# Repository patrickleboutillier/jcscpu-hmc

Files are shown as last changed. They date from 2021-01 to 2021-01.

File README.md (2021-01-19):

# jcscpu-hmc

But How Do It Know?: http://www.buthowdoitknow.com/

# Video Series

This project contains the code that runs in the implementation of John Clark Scott's CPU detailed here: 

https://www.youtube.com/playlist?list=PLYE0XunAbwfDvfabOlNWLViRcMI54M6CR

# Project Schematic
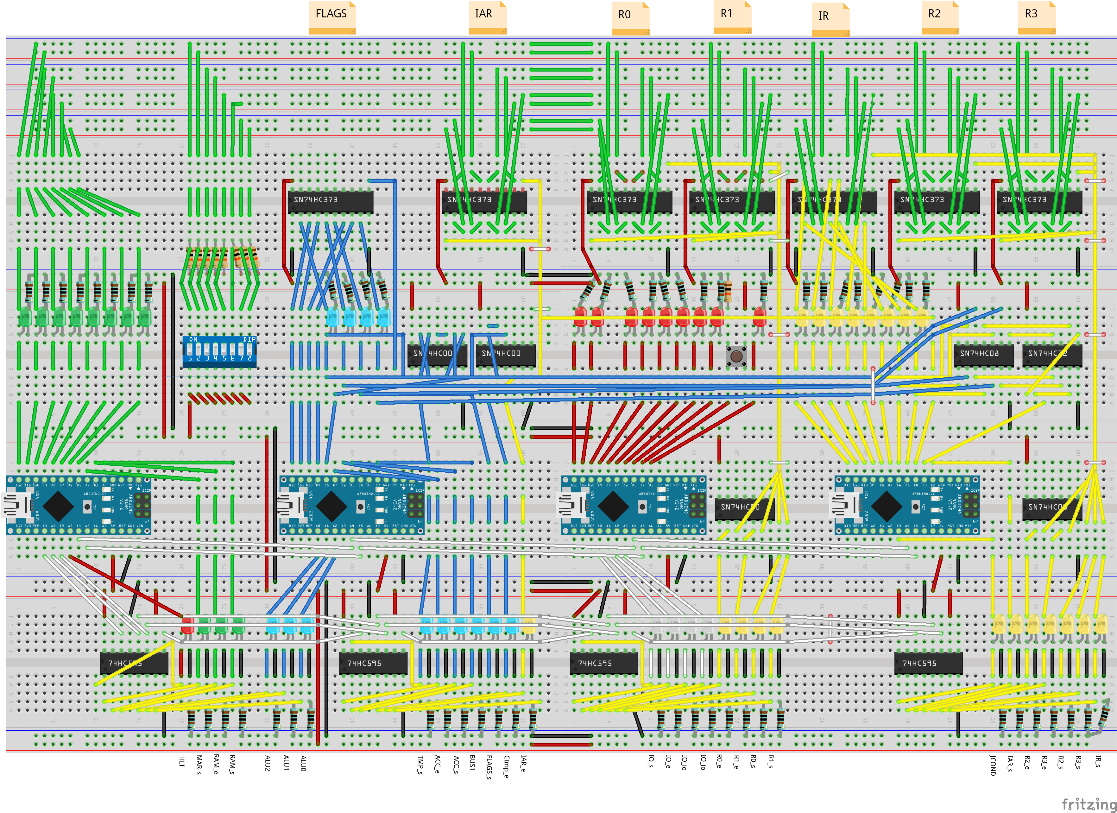
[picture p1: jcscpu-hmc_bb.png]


# Installation Instructions

## Install the Arduino IDE
- Download the IDE from https://www.arduino.cc/en/software
- Follow the instructions to install it

## Download the Arduino Code
- Download the project code from https://github.com/patrickleboutillier/jcscpu-hmc/archive/main.zip
- Unzip it on your computer, for example in *C:\Users\your_username\Documents\jcscpu-hmc-main*

## Install the Extension library
- Open the Arduino IDE
- Click on Sketch > Include Library... > Add .ZIP Library...
- Navigate to *C:\Users\your_username\Documents\jcscpu-hmc-main* and select the file named *arduino-extension-x.y.z.zip*

## Upload the code to your main Arduino

The main Arduino in the one that is located on the far left of the board.

- Open the Arduino IDE
- Click on File > Open...
- Navigate to *C:\Users\your_username\Documents\jcscpu-hmc-main\Arduino-Main* and select the file *Arduino-Main.ino*
- Click on the Compile (check mark) icon to build the project
- Connect your Arduino
- Click on the Upload (right arrow) icon to upload the code to your Arduino

If you are having issues, make sure the proper drivers are installed for your board and that the right board type and COM port are selected. 

## Upload the code to the extension Arduinos
For each extension Arduino (1, 2, or 3):
- Open the Arduino IDE
- Click on File > Open...
- Navigate to *C:\Users\your_username\Documents\jcscpu-hmc-main\Arduino-E[123]* and select the file *Arduino-E[123].ino*
- Click on the Compile (check mark) icon to build the project
- Connect your Arduino
- Click on the Upload (right arrow) icon to upload the code to your Arduino

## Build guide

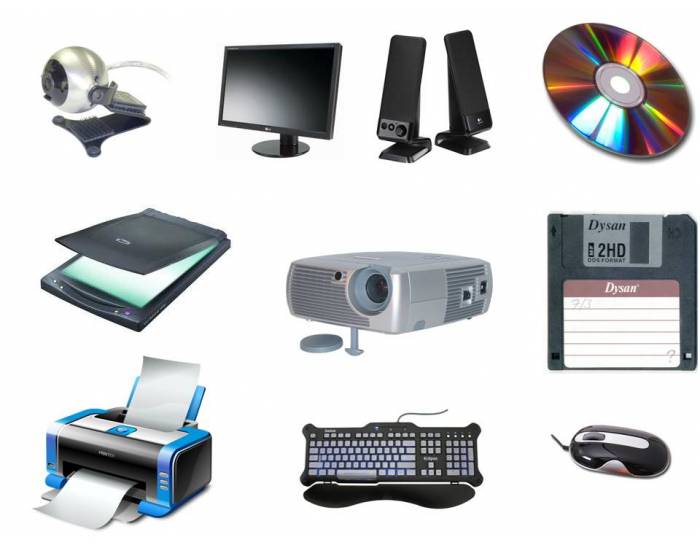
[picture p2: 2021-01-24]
Videos/29- The IO Instructions and Devices/IOdevices.jpg

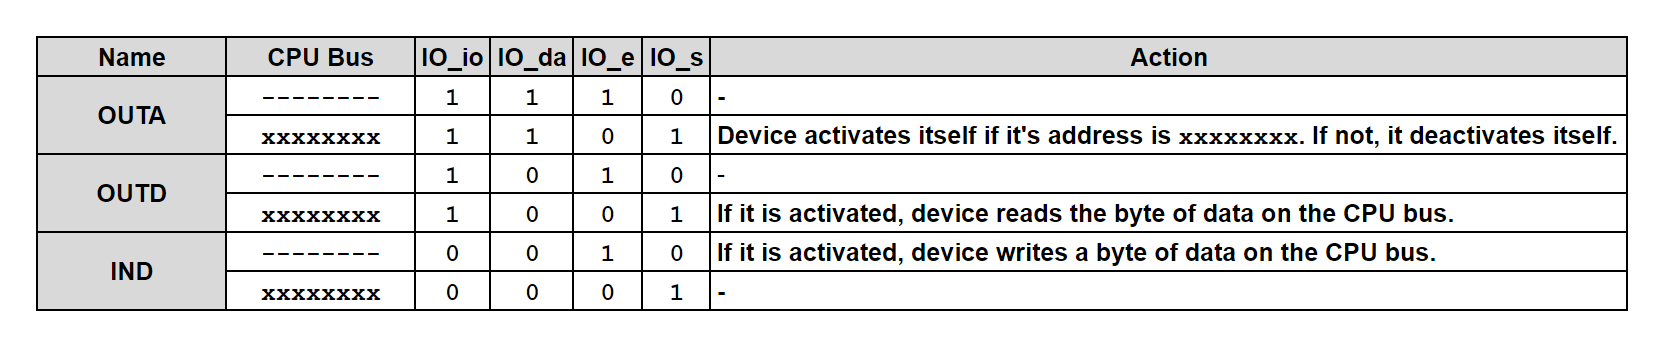
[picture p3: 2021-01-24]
Videos/29- The IO Instructions and Devices/IO_device_view.png

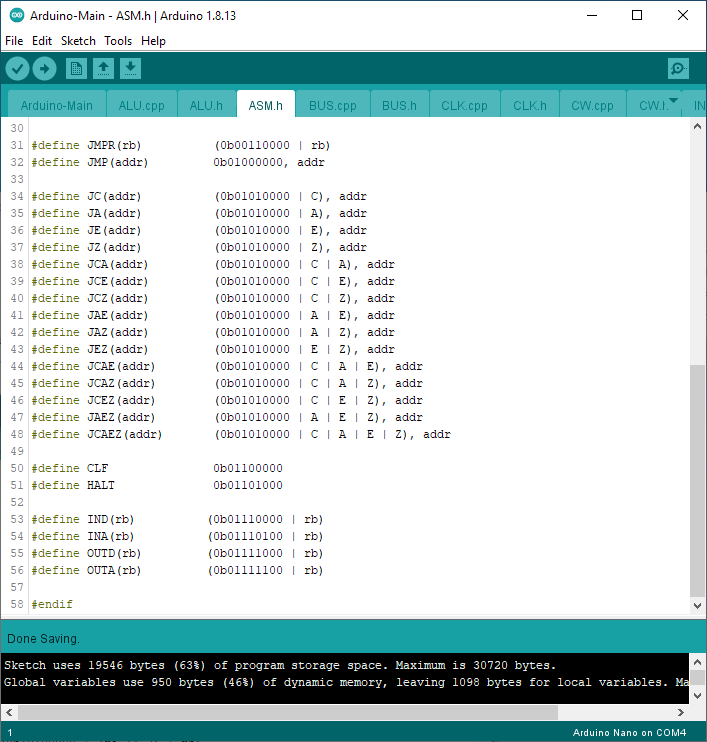
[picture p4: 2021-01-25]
Videos/30- Assembly Language and Automatic Clock/asm2.png

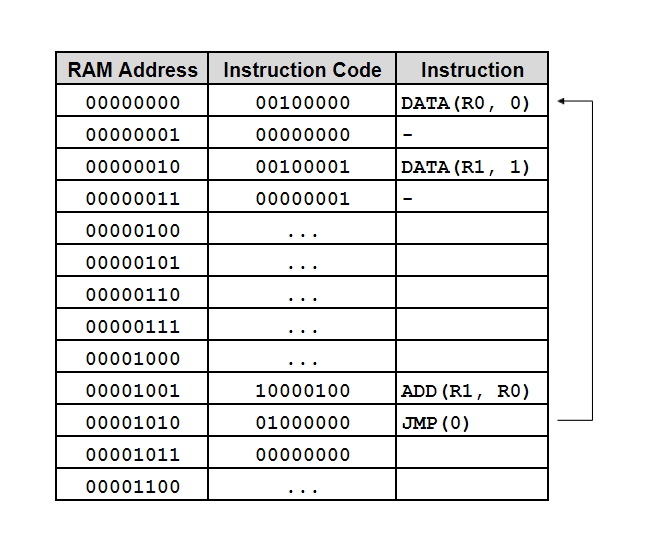
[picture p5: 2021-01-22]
Videos/27- The JMPR, JMP, JCAEZ and CLF Instructions/progjump.png

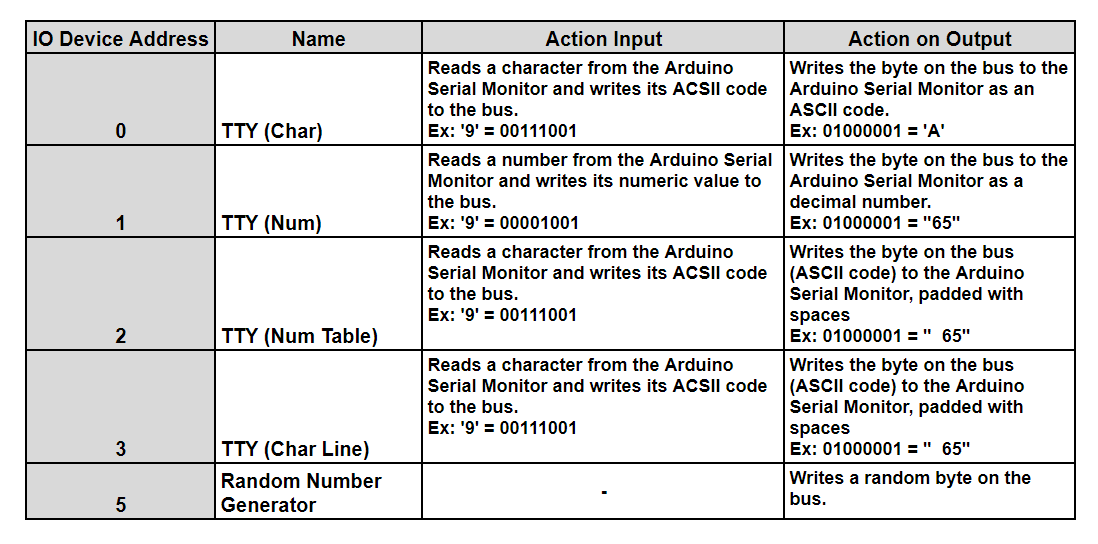
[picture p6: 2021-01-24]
Videos/29- The IO Instructions and Devices/IOdevices.png

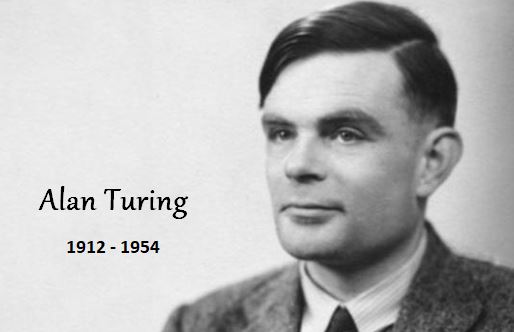
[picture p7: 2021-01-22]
Videos/27- The JMPR, JMP, JCAEZ and CLF Instructions/Alan-Turing-Facts.jpg

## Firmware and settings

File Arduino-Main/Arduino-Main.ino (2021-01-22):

#include "Extension.h"
#include "BUS.h"
#include "RAM.h"
#include "ALU.h"
#include "CLK.h"
#include "INST.h"
#include "CW.h"
#include "IO.h"
#include "PROGRAMS.h"


#define PROGRAM       NULL        // The name of the program to run. See PROGRAMS.h

#define HZ            0           // Clock speed in HZ (1 step/sec = 4, 1 inst/sec = 24, max is about 53). Use 0 for manual clock.


#define DEBUG_ON      0           // Global debug flag. Must be set to 1 for any debug info to show up.
#define ALU_DEBUG     0           // Turn on ALU debug info.
#define RAM_DEBUG     0           // Turn on RAM debug info.
#define CLK_DEBUG     0           // Turn on CLK debug info.
#define INST_DEBUG    0           // Turn on INST debug info.
#define CW_DEBUG      0           // Turn on CW debug info.
#define IO_DEBUG      0           // Turn on IO debug info.

#define RESET_MS      1000        // Reset signal duration.
#define INIT_WAIT_MS  1000        // Initial wait period after power-on.


unsigned long STARTED = 0 ;
bool RESET = true ;
bool HALTED = false ;

bool ALU_PRESENT = false ;
bool CLK_IO_PRESENT = false ;
bool INST_PRESENT = false ;

CW CW(A0, A1, A2) ;
BUS BUS(12, 11, 10, 9, 8, 7, 6, 5) ;
RAM RAM(&BUS, PROGRAM, 4, 3, 2) ;
Extension E1(1, "ALU") ;
ALU ALU(&E1, &BUS, A0, A1, A2, 8, 12, 11, 10, 9, 7, 6, 5, 4) ;
Extension E2(2, "CLK & IO") ;
CLK CLK(&E2, HZ, 4, 3, 12, 11, 10, 9, 8, 7, 6, 5) ;
IO IO(&E2, &BUS, A0, A1, A2, A3) ;
Extension E3(3, "INST & CW") ;
INST INST(&E3, 12, 11, 10, 9, 8, 7, 6, 5, A3, 3, 2, 4) ;
int pin_HLT = A3 ;


void setup(){  
  Serial.begin(9600) ;
  Serial.println(F("SYSTEM: Waiting for extention Arduinos to power up...")) ;
  Serial.println(F("SYSTEM: Wait done.")) ;
  delay(INIT_WAIT_MS) ;

  if (E1.ping()){
    Serial.print(F("SYSTEM: Extension responsible for ")) ;
    Serial.print(E1.name()) ;
    Serial.println(F(" found.")) ;
    ALU_PRESENT = true ;
    if (E2.ping()){
      Serial.print(F("SYSTEM: Extension responsible for ")) ;
      Serial.print(E2.name()) ;
      Serial.println(F(" found.")) ;
      CLK_IO_PRESENT = true ;
      if (E3.ping()){
        Serial.print(F("SYSTEM: Extension responsible for ")) ;
        Serial.print(E3.name()) ;
        Serial.println(F(" found.")) ;
        INST_PRESENT = true ;
      }
    }
  }

  RAM.setup() ;
  if (ALU_PRESENT){
    E1.enableDigitalCache() ;
    ALU.setup() ;
  }
  if (CLK_IO_PRESENT){
    E2.enableDigitalCache() ;
    CLK.setup() ;
    IO.setup() ;
  }
  if (INST_PRESENT){
    E3.enableDigitalCache() ;
    INST.setup() ;
  }

  Serial.println(F("SYSTEM: Starting power-on reset...")) ;
  STARTED = millis() ;
  RESET = true ;
  
  pinMode(pin_HLT, INPUT) ;
  HALTED = false ;
}


void loop(){
  if (HALTED){
    return ;
  }
  
  if (CLK_IO_PRESENT){
    CLK.loop(RESET, DEBUG_ON & CLK_DEBUG) ;
  }

  bool be = false ;
  be |= RAM.loop(DEBUG_ON & RAM_DEBUG) ;
  
  if (ALU_PRESENT){  
    be |= ALU.loop(DEBUG_ON & ALU_DEBUG) ;
  }
  if (INST_PRESENT){  
    if (RESET){
      byte b = BUS.read() ;
      if (b != 0){
        Serial.print(F("SYSTEM: WARNING! Bus value is not 0 (bus:")) ; 
        Serial.print(b) ; 
        Serial.println(F(") during power-on reset!")) ;         
      }
    }
    unsigned long cw = INST.loop(RESET, CLK.clk_e(), CLK.clk_s(), CLK.step(), DEBUG_ON & INST_DEBUG) ;
    // Send cw to the shift registers.
    CW.loop(RESET, cw, DEBUG_ON & CW_DEBUG) ;
  }
  if (CLK_IO_PRESENT){
    be |= IO.loop(DEBUG_ON & IO_DEBUG) ;
  }
  
  if (digitalRead(pin_HLT) == HIGH){
    Serial.print(F("SYSTEM: Halted after ")) ;
    Serial.print(millis() - STARTED) ;
    Serial.println(F("ms.")) ;
    HALTED  = true ;
  }
      
  if (! be){
    // No parts are writing to the bus, we reset it.
    BUS.reset() ;
  }
 
  // Placed here to make sure we pass at least once through the loop during RESET.
  if ((RESET)&&(millis() > STARTED + RESET_MS)){
    RESET = false ;
    Serial.println(F("SYSTEM: Reset done.")) ;
  }
}

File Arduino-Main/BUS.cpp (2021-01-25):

#include "Arduino.h"
#include "BUS.h"


BUS::BUS(int pin_bit7, int pin_bit6, int pin_bit5, int pin_bit4, int pin_bit3, int pin_bit2, int pin_bit1, int pin_bit0){  
  _enabled = false ;
  _cache = 0 ;
  _pin_bit7 = pin_bit7 ;
  _pin_bit6 = pin_bit6 ;
  _pin_bit5 = pin_bit5 ;
  _pin_bit4 = pin_bit4 ;
  _pin_bit3 = pin_bit3 ;
  _pin_bit2 = pin_bit2 ;
  _pin_bit1 = pin_bit1 ;
  _pin_bit0 = pin_bit0 ;
}


void BUS::setup(){
  pinMode(_pin_bit7, INPUT) ;
  pinMode(_pin_bit6, INPUT) ;
  pinMode(_pin_bit5, INPUT) ;
  pinMode(_pin_bit4, INPUT) ;
  pinMode(_pin_bit3, INPUT) ;
  pinMode(_pin_bit2, INPUT) ;
  pinMode(_pin_bit1, INPUT) ;
  pinMode(_pin_bit0, INPUT) ;
}


void BUS::reset(){
  if (_enabled){
    pinMode(_pin_bit7, INPUT) ;
    pinMode(_pin_bit6, INPUT) ;
    pinMode(_pin_bit5, INPUT) ;
    pinMode(_pin_bit4, INPUT) ;
    pinMode(_pin_bit3, INPUT) ;
    pinMode(_pin_bit2, INPUT) ;
    pinMode(_pin_bit1, INPUT) ;
    pinMode(_pin_bit0, INPUT) ;
    _enabled = false ;  
  }
}


byte BUS::read(){
  if (_enabled){
    // One part wants to read from the BUS, while another one is writing.
    // We give the reader the out cached value.
    return _cache ;
  }
  
  return 
    (digitalRead(_pin_bit7) << 7) |
    (digitalRead(_pin_bit6) << 6) |
    (digitalRead(_pin_bit5) << 5) |
    (digitalRead(_pin_bit4) << 4) |
    (digitalRead(_pin_bit3) << 3) |
    (digitalRead(_pin_bit2) << 2) |
    (digitalRead(_pin_bit1) << 1) |
    digitalRead(_pin_bit0) ;
}


void BUS::write(byte b){
  if (! _enabled){
    pinMode(_pin_bit7, OUTPUT) ;
    pinMode(_pin_bit6, OUTPUT) ;
    pinMode(_pin_bit5, OUTPUT) ;
    pinMode(_pin_bit4, OUTPUT) ;
    pinMode(_pin_bit3, OUTPUT) ;
    pinMode(_pin_bit2, OUTPUT) ;
    pinMode(_pin_bit1, OUTPUT) ;
    pinMode(_pin_bit0, OUTPUT) ;
    _enabled = true ;
  }

  digitalWrite(_pin_bit7, (b >> 7) & 0x01) ;
  digitalWrite(_pin_bit6, (b >> 6) & 0x01) ;
  digitalWrite(_pin_bit5, (b >> 5) & 0x01) ;
  digitalWrite(_pin_bit4, (b >> 4) & 0x01) ;
  digitalWrite(_pin_bit3, (b >> 3) & 0x01) ;
  digitalWrite(_pin_bit2, (b >> 2) & 0x01) ;
  digitalWrite(_pin_bit1, (b >> 1) & 0x01) ;
  digitalWrite(_pin_bit0, b & 0x01) ;

  _cache = b ;
}

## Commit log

2020-11-11 just coded RAM
    [jcscpu-hmc.fzz]
2020-11-14 ok, bus seems to be working
    [jcscpu-hmc.fzz]
2020-11-17 RAM, ALU ok after rework.
    [jcscpu-hmc.fzz]
2020-11-21 microcode is coming along
    [jcscpu-hmc.fzz]
2020-11-22 Added skeleton for IO and programs
    [jcscpu-hmc.fzz]
2020-11-23 before ssd upgrade
    [jcscpu-hmc.fzz]
2020-11-24 last commit before hw change
    [jcscpu-hmc.fzz]
2020-11-25 5x5 works, time to move on to the game.
    [jcscpu-hmc.fzz]
2020-11-25 added tty input via arduino Serial Monitor
2020-11-30 hll game done
    [jcscpu-hmc.fzz]
2020-12-06 image for video 4
    [1-bit Memory.fzz, jcscpu-hmc.fzz]
2020-12-07 Added squares program
    [1-bit Memory.fzz]
2020-12-09 Schematic done
    [Register.fzz, jcscpu-hmc.fzz]
2020-12-09 Final BOM
    [jcscpu-hmc.fzz]
2020-12-20 label error
    [jcscpu-hmc.fzz, jcscpu-hmc_first_half.fzz, jcscpu-hmc_ram.fzz]
2020-12-26 ALU stuff
    [jcscpu-hmc_alu.fzz]
2020-12-26 some small corrections
    [jcscpu-hmc.fzz, jcscpu-hmc_r0r1_bb.fzz, jcscpu-hmc_second_half.fzz]
2020-12-26 Starting R0 and R1
    [jcscpu-hmc_r0r1.fzz, jcscpu-hmc_r0r1_bb.fzz]
2021-01-03 clock images
    [jcscpu-hmc_clock.fzz]
2021-01-06 IR and IAR
    [jcscpu-hmc.fzz, jcscpu-hmc_ir_iar.fzz, jcscpu-hmc_r2r3.fzz]
2021-01-07 schematic errors
    [jcscpu-hmc.fzz, jcscpu-hmc_ir_iar.fzz]
2021-01-09 inst proc done
    [jcscpu-hmc_ir_iar.fzz]
2021-01-14 shift registers
    [jcscpu-hmc_cs.fzz]
2021-01-22 test run
    [jcscpu-hmc.fzz, jcscpu-hmc_flag_lines.fzz, jcscpu-hmc_flags.fzz]
2021-01-24 cleanup and IO
    [jcscpu-hmc_flags.fzz]
2021-01-25 samples done
